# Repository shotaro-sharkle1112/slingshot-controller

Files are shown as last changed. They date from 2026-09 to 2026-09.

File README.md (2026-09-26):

# 的当て名人 パチンコ型コントローラ（Slingshot Controller）

実物のゴムを引いて放す動作で遊ぶ、自作のパチンコ型ゲームコントローラです。
ゴム部分に仕込んだ曲げセンサで「引き具合」を、グリップ内のIMUで「向き」を読み取り、USBシリアルでPCへ送ります。
的当てゲーム「的当て名人」（BitSummit 2026・東京ゲームショウ2026 出展）のために作りました。

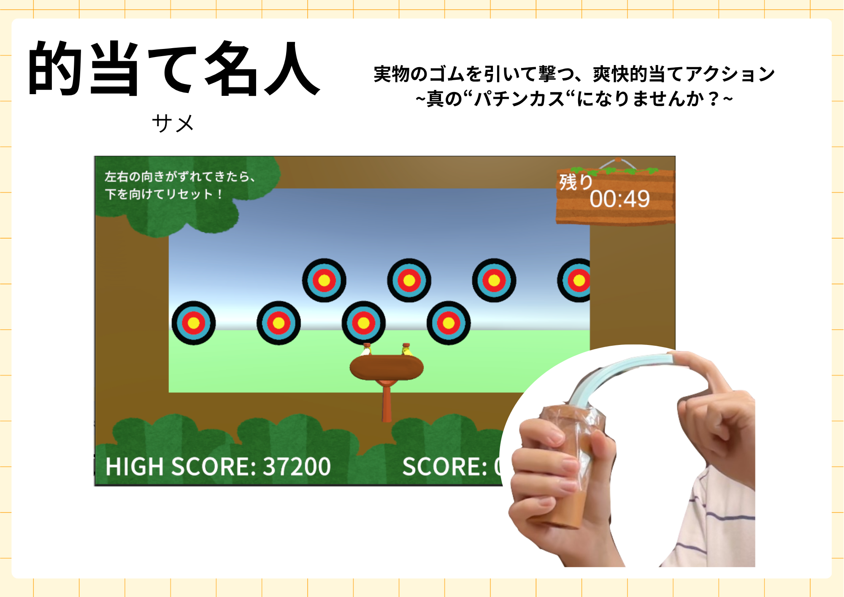
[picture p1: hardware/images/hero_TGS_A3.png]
的当て名人 パチンコ型コントローラ（TGS2026 展示用A3）


## 特徴

- **身体動作とゲーム入力が一対一で対応** — ゴムのしなり具合がそのまま弾速・威力になる
- **強さと正確さのトレードオフ** — 強く引くほど速いが、手ブレで狙いがズレる
- **部品点数が少ない** — マイコン1枚、センサ2個、抵抗1本、3Dプリント部品4種
- **プロトコルが単純** — 1行JSONを50Hzで送るだけ。Unity以外からも受け取れる

## コントローラの使い方

「的当て名人」での基本の持ち方・操作は次のとおりです。

1. 筒の部分を握り、ゴム部分（曲げセンサ）を上にしてコントローラを画面に向ける
2. ゴム部分をつまんで引く。引くほど弾は速くなるが、手ブレで狙いがズレる
3. 指を離すと発射
4. 左右の向きがずれてきたら、コントローラを下に向けて構え直す（向きがリセットされる）

**プレイヤーやクリエイターの自由な発想を推奨します。**
このコントローラは自由な形状をしているからこそ、ゴムの部分を持ったり、振り回したり、このパチンコゲームとは違った遊び方ができるかもしれません。ゲームを作る側も、「引く」以外の入力として曲げセンサとIMUを組み合わせてみてください。
新しい遊び方やゲームが完成したら、ぜひ共有していただけると嬉しいです（X: [@tDo8GKZwwU86364](https://x.com/tDo8GKZwwU86364)）。

## 構成

```
┌─ コントローラ ────────────────────┐   USBシリアル   ┌─ PC ────────────────────┐
│ 曲げセンサ BS-85 ──(分圧 10kΩ)── ADC0 │ ────────────→ │ 受信スレッド → JSON解析 │
│ MPU6050 ───────────(I2C)──── Pico W │ 115200 / JSON │ → 姿勢推定（相補フィルタ）│
└──────────────────────────────────┘   50 Hz         │ → ゲームへ反映            │
                                                     └────────────────────────┘
```

| 部位 | 内容 |
|---|---|
| マイコン | Raspberry Pi Pico W（MicroPython 1.28.0） |
| 引き具合 | センシアテクノロジー 高性能曲げセンサ BS-85（抵抗変化型）＋ 10 kΩ 分圧 → ADC0（GP26） |
| 向き | MPU6050（6軸IMU）→ I2C0（GP0/GP1） |
| 筐体 | PLAのグリップ筒（3Dプリント）＋ TPUのセンサカバー（3Dプリント） |
| 接続 | USBケーブル（バスパワー） |

## リポジトリ構成

```
hardware/
  wiring.svg / wiring.png     配線図
  BOM.md                      部品表
  3d/grip.stl                 グリップ（筒×3、TPUカバーがハマるフタ）
  3d/bendsensor_cover.3mf     曲げセンサカバー（TPU）
  images/                     写真
firmware/
  main.py                     Pico W 用（MicroPython）
  imu.py, vector3d.py         MPU6050 ドライバ（MIT, Peter Hinch / Sebastian Plamauer）
unity/
  ControlerManager.cs         Unity 側の受信スクリプト
LICENSE.md                    ライセンスの要約と商用利用の連絡先
LICENSE-HARDWARE.txt          CC BY-NC-SA 4.0 全文
LICENSE-SOFTWARE.md           PolyForm Noncommercial 1.0.0 全文
THIRD_PARTY_NOTICES.md        同梱した第三者コードのライセンス
```

## 作り方

### 1. 部品

[hardware/BOM.md](hardware/BOM.md) を参照。主要部品は Pico W、MPU6050 モジュール、BS-85、10 kΩ 抵抗、ユニバーサル基板、USBケーブル。

### 2. 配線

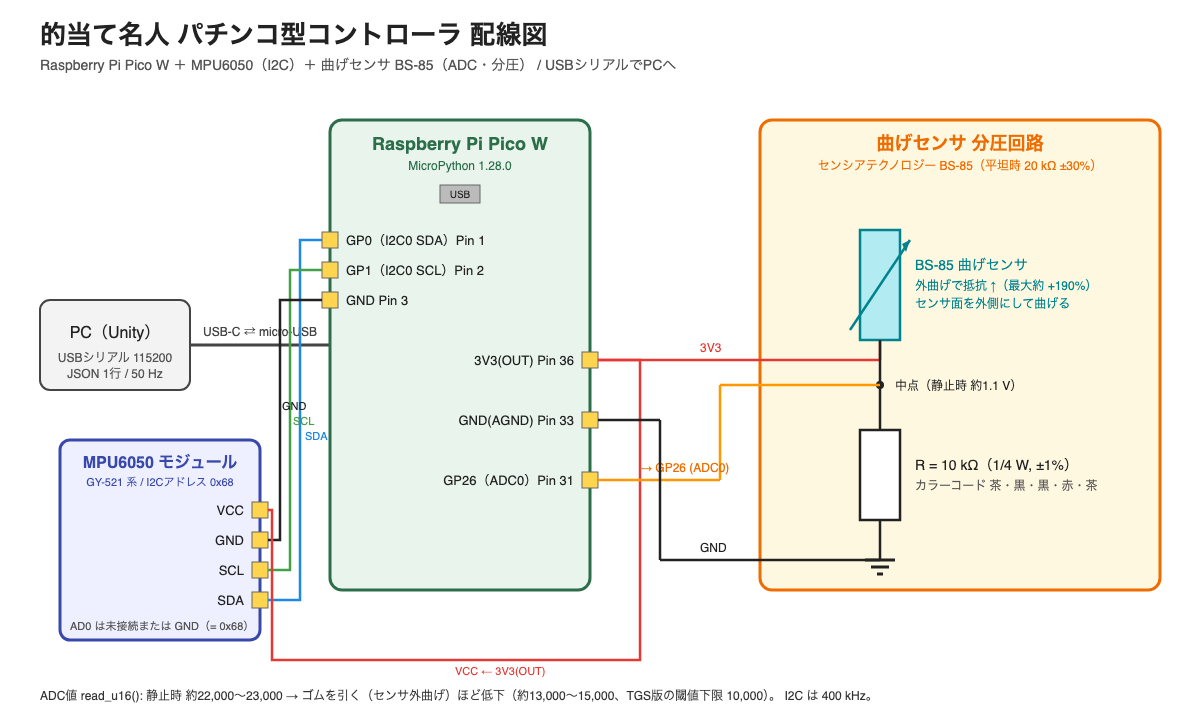
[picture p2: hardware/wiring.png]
配線図


| Pico W | 接続先 |
|---|---|
| GP0（Pin 1） | MPU6050 SDA |
| GP1（Pin 2） | MPU6050 SCL |
| 3V3(OUT)（Pin 36） | MPU6050 VCC、曲げセンサの一端 |
| GND | MPU6050 GND、10 kΩ 抵抗の一端 |
| GP26 / ADC0（Pin 31） | 曲げセンサのもう一端 ＝ 10 kΩ 抵抗のもう一端（分圧の中点） |

- 曲げセンサは **センサ面（金属パターンが見える面）を外側**にして曲がるように取り付けると抵抗が上がり、ADC値が下がります。静止時 約22,000、強く引いて 約10,000〜15,000（16bit）
- センサ端子のはんだ付けは 190 ℃以下の低温はんだを推奨（基材がPET）

### 3. 3Dプリント

| 部品 | ファイル | 材料 | 数 |
|---|---|---|---|
| グリップ筒（外径45・内径40・高さ30 mm） | `hardware/3d/grip.stl` | PLA | 3（うち1つは端面に角穴つき。ケーブルを出す側） |
| TPUカバーがハマるフタ（外径50・高さ10 mm、センサ用スリット 20.5×9 mm） | `hardware/3d/grip.stl` | PLA | 1 |
| 曲げセンサカバー（140×20×4 mm、浅い凹みつき） | `hardware/3d/bendsensor_cover.3mf` | TPU | 2 |

プリント設定: 0.4 mm ノズル、スライサーの既定設定で印刷できます（Bambu Studio で確認）。
**TPU のカバーはインフィル 100% を推奨**します（展示版は既定の 15% で印刷しましたが、100% の方が良い）。そのほかの設定は自由に変えて構いません。

| グリップの4パーツ（grip.stl） | TPU カバー（bendsensor_cover.3mf） |
|---|---|
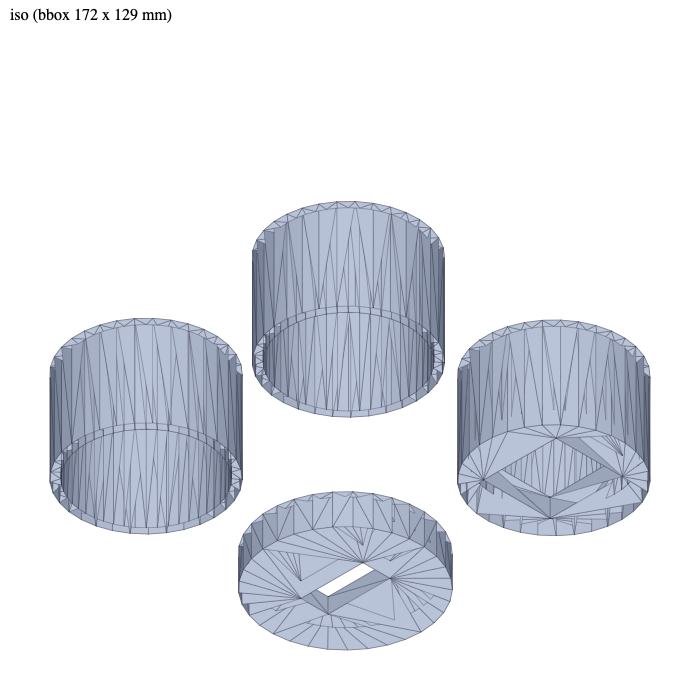
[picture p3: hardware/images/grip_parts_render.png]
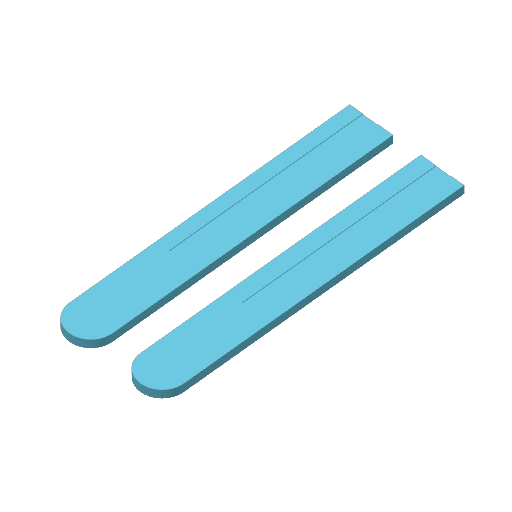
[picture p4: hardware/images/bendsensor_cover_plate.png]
|  |  |

### 4. 組み立て

**基板**

1. ユニバーサル基板を幅 40 mm 以下にカットし、Pico W（ピンヘッダ）と MPU6050 モジュール、10 kΩ 抵抗を実装して配線する
2. 曲げセンサの端子に配線をはんだ付けし（低温はんだ）、基板の ADC0 側・3V3 側へ接続する
   ※ **曲げセンサは繊細です。作業中に折らないよう注意**してください

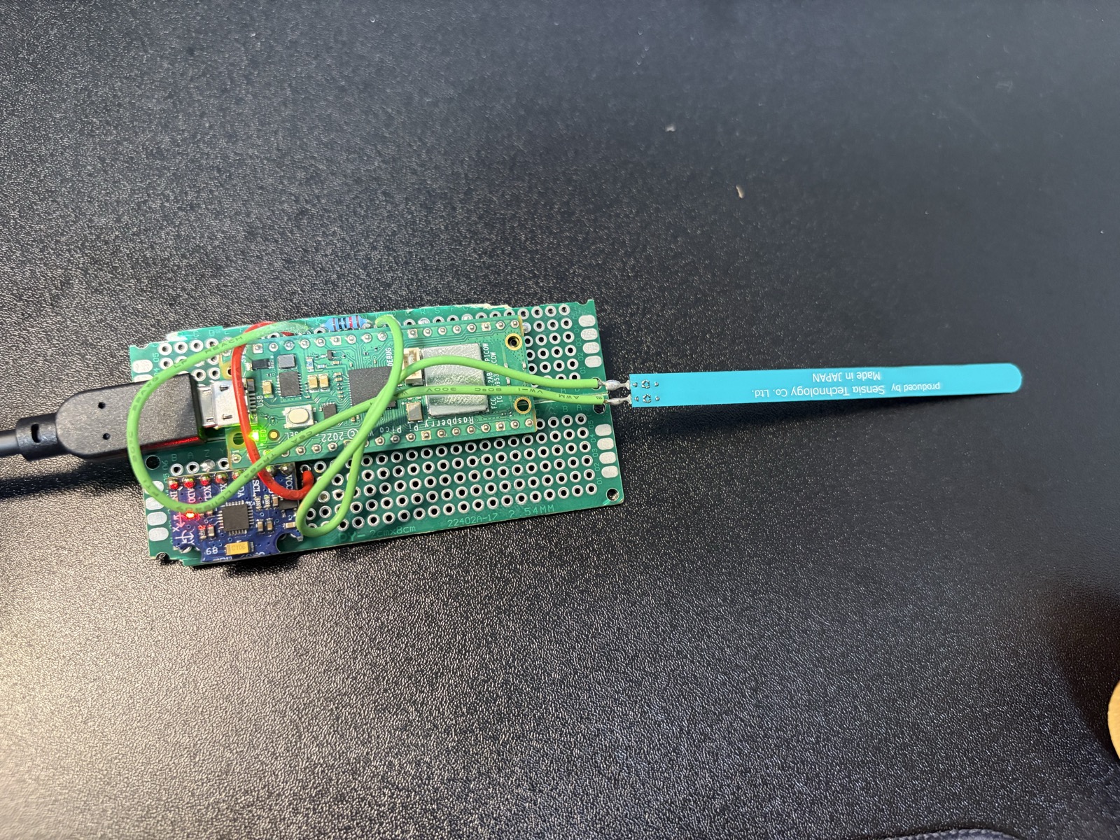
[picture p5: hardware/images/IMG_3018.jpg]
はんだ付け済みの基板


**プリント部品の接着（2つの組み立て品を作る）**

3. **上側**: TPU カバーがハマるフタ ＋ 筒 1 つ ＋ TPU カバー をゴリラグルーで接着する。TPU カバーは 2 枚を凹み同士で合わせ、**センサが入る隙間以外を接着**してポケットを作り、フタのスリットの位置に固定する
4. **下側**: 筒 1 つ ＋ 端面に角穴のある筒 をゴリラグルーで接着する（角穴からケーブルを出す）
   どちらも、接着剤が乾くまでテープで仮固定する

**挿入**

5. はんだ付け済みの基板を、接着済みのプリント部品に挿入する。曲げセンサを上側のフタのスリットに通して TPU カバーのポケットへ差し込み、基板を下側の筒へ収める
6. 上側と下側を合わせて固定する。固定は**テープを推奨**

| 手順 | 写真 |
|---|---|
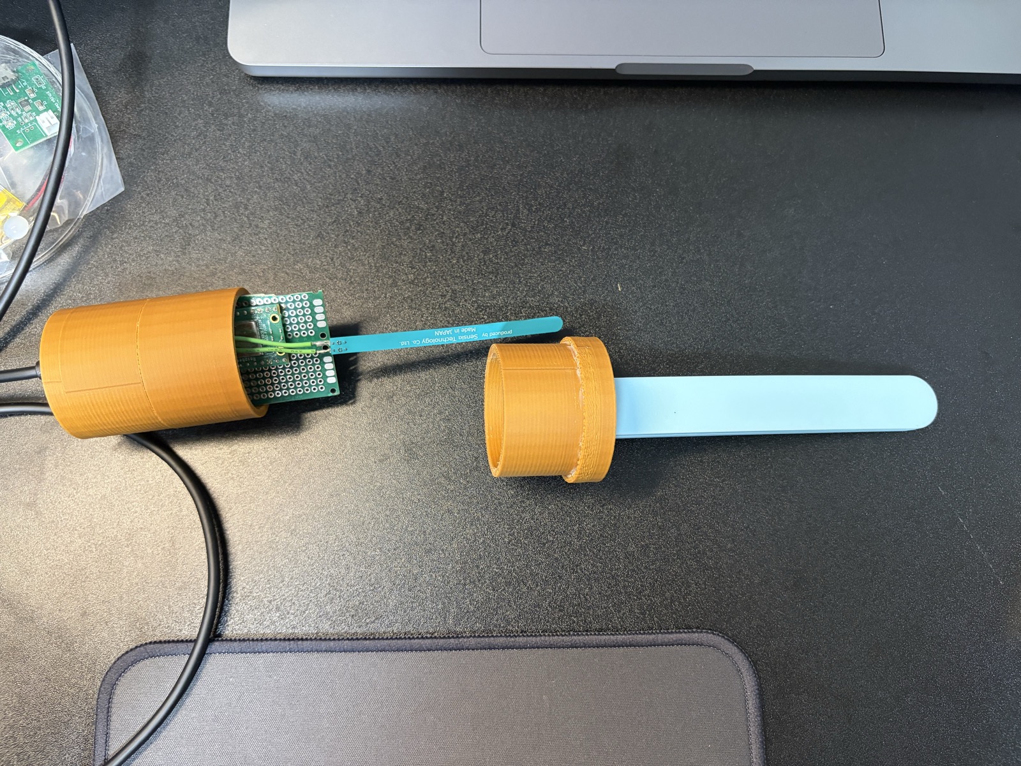
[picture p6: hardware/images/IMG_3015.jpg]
| 部品が揃った状態 |  |
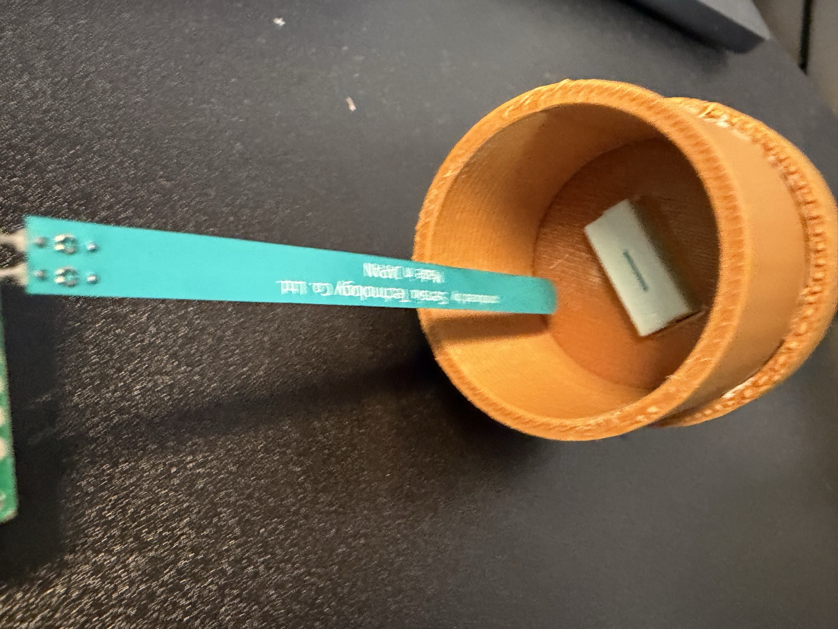
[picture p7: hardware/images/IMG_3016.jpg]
| 曲げセンサをスリットに通す |  |
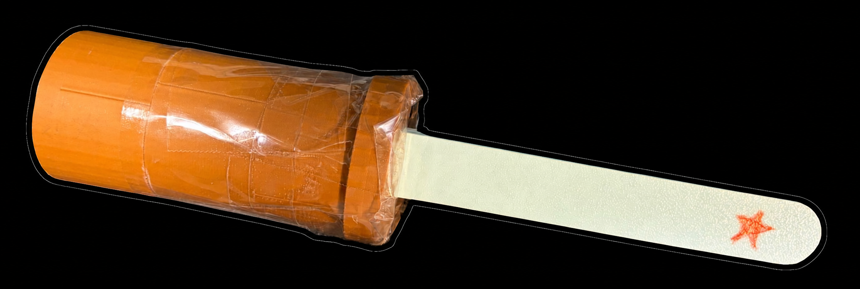
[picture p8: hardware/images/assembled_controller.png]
| 組み立て済みのコントローラ |  |

### 5. ファームウェア

1. Pico W に MicroPython 1.28.0 の UF2 を書き込む
2. Thonny で `firmware/main.py`, `imu.py`, `vector3d.py` を Pico に保存する
3. USB 接続すると自動起動し、50 Hz で JSON を送り始める（動作中は本体 LED が点滅）

### 6. 通信プロトコル

USB CDC シリアル（115200 bps）、1 行 1 パケット、末尾 `\n`、50 Hz。

```json
{"t_ms":12345,"bend":21800,"accel":{"x":0.01,"y":0.02,"z":1.01},"gyro":{"x":0.1,"y":-0.2,"z":0.3}}
```

| フィールド | 意味 | 単位 |
|---|---|---|
| t_ms | Pico 起動からの経過時間 | ms |
| bend | 曲げセンサの ADC 生値（read_u16） | 0〜65535 |
| accel | 加速度（±4 g レンジ） | g |
| gyro | 角速度（±1000 dps レンジ、41 Hz LPF） | deg/s |

エラー時は `{"error":"..."}` を送ります。

### 7. Unity で受け取る

`unity/ControlerManager.cs` をシーンに置き、Inspector の Port Name にシリアルポート名（macOS: `/dev/cu.usbmodem*`、Windows: `COM*`）を入れます。
受信は別スレッドで行い、`FixedUpdate` でキューから取り出して `Bend` / `Accel` / `Gyro` プロパティに反映します。
向きの推定やゲームへの反映はゲーム側の実装に任せています（このリポジトリには含みません）。

## 展示実績

- BitSummit 2026（京都）— 約150人がプレイ
- EC2026（京都産業大学）
- 東京ゲームショウ 2026（神ゲー創造主エボリューション 2026 二次審査通過作品として出展）

## 既知の課題・今後

- ゴム（TPU）部分が長期使用で少しずつ変形する
- 左右の向き（ヨー）はIMU単体では補正できないため、下を向いて構え直すリセット操作をゲーム側で用意している。磁気センサの追加を検討中
- トリガーボタンの追加、ネジ止めの蓋、握りやすいカバー形状（改良案）

## ゲーム本体

「的当て名人」のビルド版: 準備中（配布先が決まり次第ここに載せます）

## ライセンス

本プロジェクトは **非商用に限り** 自由に利用・改変・再配布できます。商用利用（キットや完成品の販売、有料ゲームへの組み込みなど）を希望する場合は、下記の連絡先までご相談ください。個別にライセンスします。

- ハードウェア（回路図・3Dデータ・図面・組立手順・写真）: **CC BY-NC-SA 4.0**（クレジット表示・非商用・改変版は同条件で共有）
- ファームウェア（`firmware/main.py`）・Unity スクリプト（`unity/ControlerManager.cs`）: **PolyForm Noncommercial 1.0.0**
- `firmware/imu.py`, `vector3d.py` は Sebastian Plamauer / Peter Hinch による **MIT ライセンス**のコードです（原ライセンスのまま）
- 商用ライセンスの問い合わせ: matsumatsu1112@icloud.com

非商用ライセンスのため、OSHWA／OSI の定義上の「オープンソース」ではなく、「設計とソースの公開（非商用）」です。全文は [LICENSE-HARDWARE.txt](LICENSE-HARDWARE.txt)、[LICENSE-SOFTWARE.md](LICENSE-SOFTWARE.md)、要約は [LICENSE.md](LICENSE.md) を参照してください。

**License (English)**
This project is published for **non-commercial use only**.
Hardware (schematics, 3D files, drawings, assembly instructions, photos): CC BY-NC-SA 4.0.
Firmware and Unity scripts: PolyForm Noncommercial 1.0.0. `imu.py` / `vector3d.py` remain under their original MIT license.
Selling kits, finished units, or clones of this controller, or including it in a commercial product, requires a separate commercial license. For commercial licensing, contact: matsumatsu1112@icloud.com

## 作者

サメ — X: [@tDo8GKZwwU86364](https://x.com/tDo8GKZwwU86364)

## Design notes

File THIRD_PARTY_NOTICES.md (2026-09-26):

# Third-party notices / 同梱した第三者コード

## firmware/imu.py, firmware/vector3d.py

MicroPython driver for InvenSense IMUs (MPU6050 base class), adapted from the `micropython-mpu9150` / `micropython-mpu9250` drivers.

- Authors: Sebastian Plamauer, Peter Hinch
- Source: https://github.com/micropython-IMU/micropython-mpu9150
- License: MIT License (Copyright (c) 2014 Sebastian Plamauer, oeplse@gmail.com, Peter Hinch)

The full MIT license text is included in the header of `firmware/imu.py` and `firmware/vector3d.py`. These files are redistributed under their original MIT license and are **not** covered by the PolyForm Noncommercial license used for the rest of the firmware.

## Sensor datasheet

The bend sensor (Sensia Technology BS-85) datasheet is not included in this repository. See https://www.sensia.jp/pages/5643889/page_202112191229

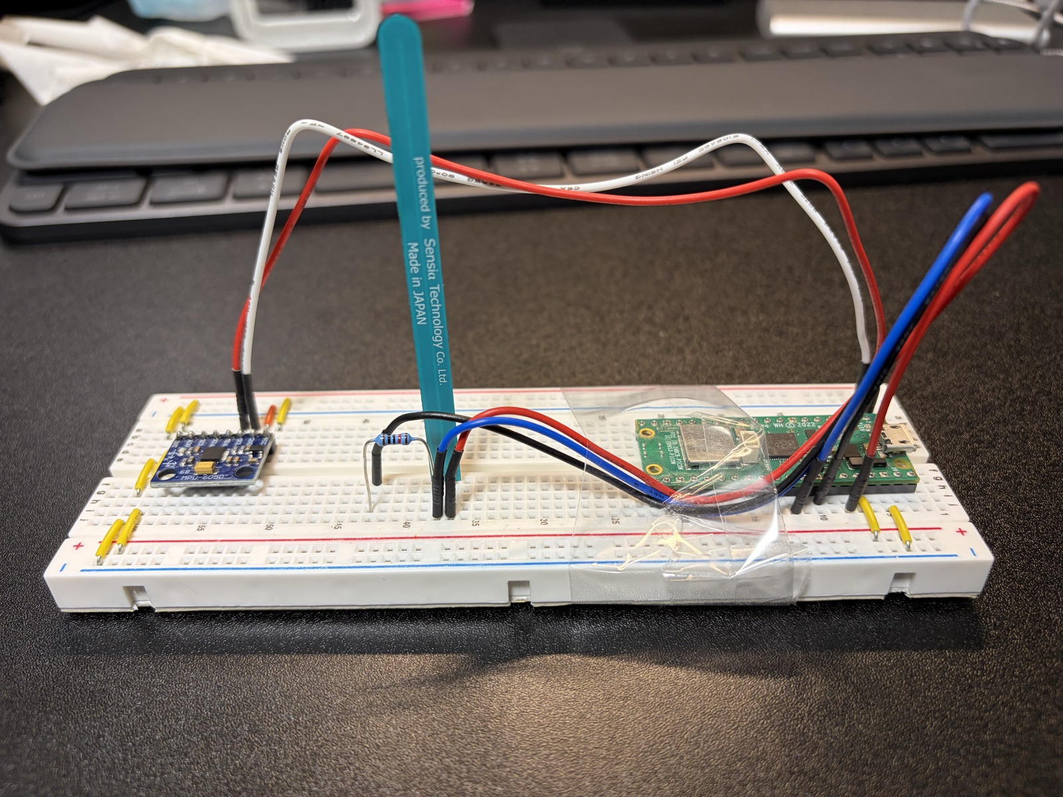
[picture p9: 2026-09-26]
hardware/images/breadboard_prototype.jpg

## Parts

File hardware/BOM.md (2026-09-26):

# 部品表（BOM） — 的当て名人 パチンコ型コントローラ

作成: 2026-09-26（写真・ファーム・3Dデータから起こしたもの。購入先は記載しない方針）
数量は1台分。

## 電子部品

| # | 部品 | 仕様・型番 | 数量 | 備考 |
|---|---|---|---|---|
| 1 | マイコンボード | Raspberry Pi Pico W（RP2040、micro-USB） | 1 | MicroPython 1.28.0 を書き込む。ピンヘッダ経由でユニバーサル基板にはんだ付け |
| 2 | ピンヘッダ | 2.54 mm ピッチ オス 20ピン | 2 | Pico W を基板に実装するため（Pico Hなら不要） |
| 3 | IMU モジュール | MPU6050 搭載ブレークアウト（GY-521 系、I2C、3.3 V 動作） | 1 | 使用ピン: VCC / GND / SCL / SDA。AD0 未接続または GND（アドレス 0x68） |
| 4 | 曲げセンサ | センシアテクノロジー 高性能曲げセンサ **BS-85**（センサ部 85 mm、全長 89.5 mm、幅 6 mm、厚さ 0.2 mm 以下、平坦時 20 kΩ ±30%） | 1 | 端子ピッチ 2.54 mm。はんだ付けは 190 ℃以下の低温はんだ推奨（基材 PET） |
| 5 | 抵抗 | 10 kΩ 1/4 W ±1%（金属皮膜、カラーコード 茶・黒・黒・赤・茶） | 1 | 曲げセンサの分圧用プルダウン |
| 6 | ユニバーサル基板 | 2.54 mm ピッチ 片面ガラエポ（写真の基板は約 45 × 70 mm、グリップ内径 40 mm に収まる幅） | 1 | 幅 40 mm 以下にカットして使う |
| 7 | 配線材 | 単芯ワイヤ（写真では緑・赤、AWG 22〜24 相当） | 少量 | I2C 4本、センサ 2本、電源 |
| 8 | USB ケーブル | USB-C（PC側）⇄ micro-USB（Pico側）、データ通信対応 | 1 | 電源も兼ねる。長さは展示環境に合わせる |
| 9 | はんだ | 低温はんだ（センサ端子用）＋ 通常のはんだ | 少量 | センシアの推奨: 190 ℃以下 |

## 3Dプリント部品

| # | 部品 | データ | 材料 | 数量 | 寸法（データより） |
|---|---|---|---|---|---|
| 10 | グリップ筒 | `3d/grip.stl` 内 part 1, 3 | PLA | 2 | 外径 45 / 内径 40 / 高さ 30 mm（肉厚 2.5 mm） |
| 11 | グリップ筒（端面に角穴・ケーブル側） | `3d/grip.stl` 内 part 2 | PLA | 1 | 外径 45 / 内径 40 / 高さ 30 mm、高さ 6 mm 位置に角穴つきの床 |
| 12 | TPUカバーがハマるフタ（センサ通し） | `3d/grip.stl` 内 part 0（＝`huta.stl`） | PLA | 1 | 外径 50 × 高さ 10 mm。内径 46 × 深さ 5 mm の受け口に筒が入る。床にセンサ用スリット 20.5 × 9 mm |
| 13 | 曲げセンサカバー | `3d/bendsensor_cover.3mf`（元 STL: bendsensor_cover.stl） | TPU | 2 | 140 × 20 × 4 mm、片端 R10。片面に 10 × 90 × 0.32 mm の浅い凹み（センサ収納） |

- 3Dプリンタ: Bambu Lab（BambuStudio 02.06 でスライス）。グリップは PLA、カバーは TPU
- プリント設定: 0.4 mm ノズル・既定設定。**TPU カバーはインフィル 100% 推奨**（展示版は 15% で印刷、100% の方が良い）
- グリップの元データは Tinkercad。FreeCAD での再モデリングを予定

## 副資材

| # | 品目 | 用途 |
|---|---|---|
| 14 | ゴリラグルー（多用途接着剤） | 筒同士・キャップ・カバーの接着 |
| 15 | テープ | 組み立て時の仮固定・補強 |

## 参考: 1台あたりの部品費の目安

主要部品（Pico W、MPU6050 モジュール、BS-85、基板・抵抗・配線・ケーブル）で 4,000〜5,000 円程度。フィラメントは数十グラム。

## 出典

- 部品構成: `images/IMG_3018.jpg`（基板全景）、`images/IMG_3019.jpg`（抵抗のカラーコード）、`images/breadboard_prototype.jpg`（BitSummit時の試作）
- センサ仕様: センシアテクノロジー BSシリーズ データシート（https://www.sensia.jp/pages/5643889/page_202112191229）
- 3D寸法: `3d/grip.stl`, `3d/bendsensor_cover.3mf` のメッシュ解析（2026-09-26）

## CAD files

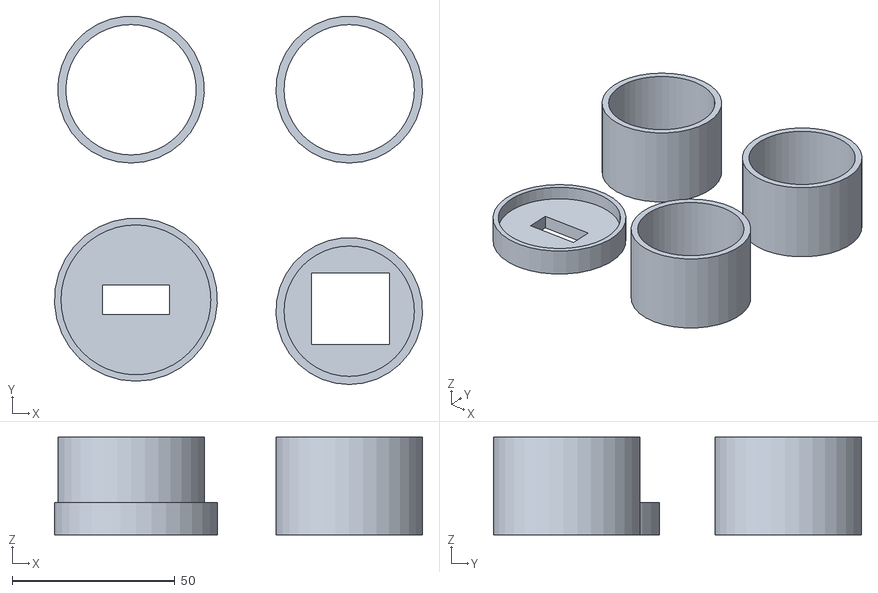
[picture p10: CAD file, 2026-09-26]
hardware/3d/grip.stl
113.0 x 113.0 x 30.0

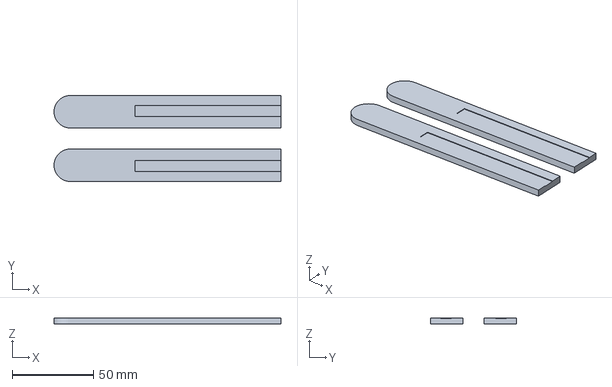
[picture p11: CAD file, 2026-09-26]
hardware/3d/bendsensor_cover.3mf
140.0 x 53.0 x 4.00 mm

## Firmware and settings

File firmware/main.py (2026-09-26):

# combined_bend_mpu_serial.py
# Pico W / MicroPython
# USBシリアルで Unity にセンサ値を送信する
#
# 出力例:
# {"t_ms":12345,"bend":30120,"accel":{"x":0.01,"y":0.02,"z":1.01},"gyro":{"x":0.1,"y":0.2,"z":0.3}}

import time
import sys

try:
    import ujson as json
except ImportError:
    import json

from machine import ADC, Pin, I2C
from imu import MPU6050  # imu.py が Pico 側に必要

led = Pin("LED", Pin.OUT)

# =========================
# 送信周期
# =========================
# 20ms = 50Hz
SEND_INTERVAL_MS = 20

# =========================
# 曲げセンサ / ADC
# =========================
# ADC0 = GPIO26
bend_sensor = ADC(Pin(26))

latest_raw = 0
latest_ema = 0.0
EMA_ALPHA = 0.3


def update_bend_raw():
    """曲げセンサのADC raw値を更新する。read_u16() は 0〜65535 を返す。"""
    global latest_raw, latest_ema

    latest_raw = bend_sensor.read_u16()
    latest_ema = EMA_ALPHA * latest_raw + (1 - EMA_ALPHA) * latest_ema

    return int(latest_raw)


# =========================
# I2C & MPU6050
# =========================
# 配線例: GP0→SDA, GP1→SCL, 3V3→VCC, GND→GND, AD0→GND(=0x68)
i2c = I2C(0, sda=Pin(0), scl=Pin(1), freq=400000)
mpu = MPU6050(i2c)

# 元コードと同じ設定
mpu.accel_range = 1
mpu.gyro_range = 2
mpu.filter_range = 2  # 41Hz


def read_mpu():
    """MPU6050の加速度・角速度をdictで返す。"""
    ax, ay, az = mpu.accel.xyz  # g
    gx, gy, gz = mpu.gyro.xyz   # deg/s

    return {
        "accel": {
            "x": ax,
            "y": ay,
            "z": az
        },
        "gyro": {
            "x": gx,
            "y": gy,
            "z": gz
        }
    }


def make_payload():
    bend = update_bend_raw()
    mpu_data = read_mpu()

    return {
        "t_ms": time.ticks_ms(),
        "bend": bend,
        "accel": mpu_data["accel"],
        "gyro": mpu_data["gyro"]
    }


def send_json(payload):
    # Unity 側で ReadLine() しやすいように、必ず末尾に \n を付ける
    line = json.dumps(payload)
    sys.stdout.write(line + "\n")


# =========================
# メインループ
# =========================
counter = 0

while True:
    try:
        payload = make_payload()
        send_json(payload)

        # 動作確認用LED
        counter += 1
        if counter % 25 == 0:
            led.toggle()

    except Exception as e:
        # エラーもJSON形式で送る
        error_payload = {
            "error": str(e)
        }
        send_json(error_payload)

    time.sleep_ms(SEND_INTERVAL_MS)
